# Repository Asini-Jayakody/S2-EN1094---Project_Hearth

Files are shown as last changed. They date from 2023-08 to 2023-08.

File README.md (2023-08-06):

# S2-EN1094
 Engineering Design Project Semester 02

Back in my early days in the department (second semester), I had the opportunity to work on an innovative project under the module EN1094. Our team decided to address a major issue that many people experienced at the time: the unavailability and high expense of fuel gasoline.
To solve this, we set out to create a long-term solution: a coconut shell stove.

Choosing this project was an eye-opening experience because we found the major problems involved with traditional coconut shell stoves. These stoves took an inordinate amount of time to light the charcoal, and once lit, they lacked an efficient mechanism of controlling the temperature.

With our collective enthusiasm and determination, we devised an ingenious solution: a hearth equipped with a DC fan to precisely control the heat output based on user input. The system operated on a 12V DC fan and incorporated a MAX6675 temperature sensor to monitor and maintain the desired temperature levels.

The result of our hard work was remarkable!

We succeeded in offering users six different temperature ranges, allowing them to select the most suitable one based on their specific needs. As we valued user interaction and feedback, we incorporated an OLED display and a buzzer as indicators to enhance the overall user experience.

Working in a team( with Dulini Himeka , Selani Indrapala , Jathurshan S. ) was an amazing experience! We collaborated closely, sharing ideas and supporting one another throughout the project's development. It was inspiring to witness the power of teamwork in overcoming challenges and achieving our common goal.

Presenting our hearth project at the end of the semester was a moment of immense pride and accomplishment. Not only we created an innovative solution to a real-world problem, but we also gained valuable insights into the realm of electronic design.

This project served as my first step into the world of electronic design, sparking my passion for technology and the limitless possibilities it offers. I am immensely grateful for the hands-on experience, the challenges, and the camaraderie that defined this journey.

Looking back, I cherish the memories of working together with my talented team, pushing the boundaries of creativity and engineering knowledge. The success of our hearth project on both technical and collaborative fronts has motivated me to pursue further electronic design projects, fostering a desire to continually learn and create impactful solutions for the world.

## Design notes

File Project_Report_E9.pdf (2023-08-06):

## Department of Electronic & Telecommunication Engineering

## University of Moratuwa

# Hearth

### Group EN09

200222K | HIMEKA S.H.D.
200232P | INDRAPALA S.A.
200239T | JATHURSHAN S.
200242V | JAYAKODY J.A.A.U.

This report is submitted for module EN1190

07th October 2022

## Abstract

The hearth regulates the temperature of the fire as per the user requirement by using the reading taken from the temperature sensor and regulating the DC fan speed accordingly. The hearth has a user interface which allows the user to turn a knob to their required temperature range and the selected range will be displayed on the OLED. Additionally, the hearth also has a buzzer going off if there are any abnormalities when functioning. The enclosure for the hearth was designed using SolidWorks and attention was given to the materials employed. The PCB was designed using Altium.

## Contents

### Introduction

The hearth takes into consideration the input temperature range by the user as well as the
current | temperature | reading | from | the
temperature sensor and will change the fan speed in order to bring the temperature into the users’ temperature range. The main components of the device are,
- ATmega328P-PU
- MAX6675 Temperature Sensor
- OLED
- 100K Potentiometer
- 12V DC fan
- L9110 Motor Driver Module
- 12V Power Pack

The device gives the user an option of 6 temperature ranges and has a buzzer and a display to notify the user of the selected temperature range and if there is an issue in the functionality.

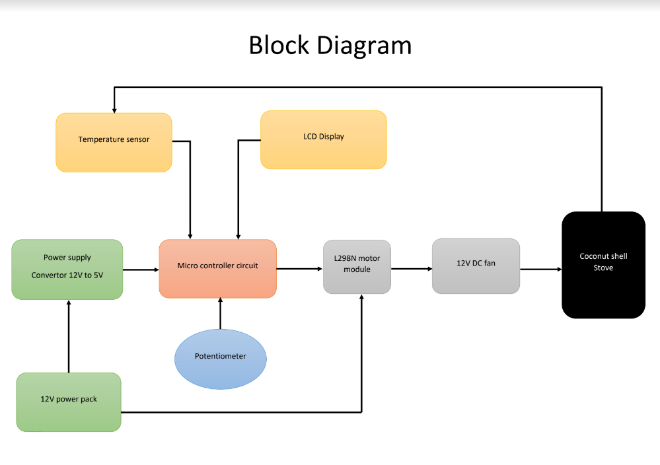
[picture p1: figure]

Figure 1.1: Block Diagram of the Device

### Product Description

Design Idea

Given the shortage of gas cylinders and the hike of gas cylinder prices in the recent past in Sri Lanka, most people have been turning to using electric induction cookers or hearths. Since electricity prices as well as induction cooker prices have also increased, most households have been using traditional hearths.

Motivation

However, these hearths have potential to be improved to make the cooking experience more user friendly. The existing market products can be seen to lack the following features,

- User must keep blowing into the flame to control the flame. Even the hearths with DC fans have an unreliable increase and reduction in temperatures such that the user must consistently be present to adjust fan speeds.
- Soot depositions on cooking utensils and the stove.
- Cleaning the ash leftovers after usage.
- Smokes released are disturbing.

Who Benefits?

Our device would cater to most lower to middle class households as it could reduce the costs associated with gas cylinders as well as electricity.

### Product Idea Validation

Hearths have a lot of room for improvement. However, the main problem we chose to focus on was the fact that the user must be in constant vicinity of the hearth to ensure that the heat from the fire is regulated at the needed level. This would be a waste of time for the consumer.

Therefore, our solution was to build a hearth with a DC fan which would regulate the heat in the needed level once the user has input their requirement.

To ensure that this was a requirement of our target market we conducted a survey through which we collected the following data.

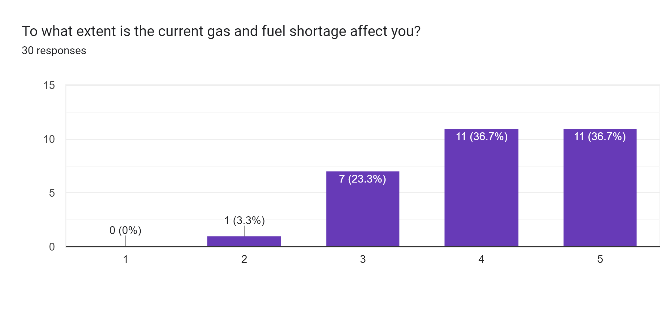
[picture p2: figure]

Figure 3.1: The extent to which users were affected by the gas shortage.

As seen by Figure 3.1, more than 50% of users were highly affected by the gas shortage. Therefore, an alternative for gas cookers is necessary.

Figure 3.2: Will the user buy our product?

On explaining the product, we had in mind, most users showed positive responses whereas a few were unsure but none of the users believed that the product was not needed.

Figure 3.3: User needs.

We then took this opportunity to check what the user expected of this product and on designing the product we took into consideration most of these factors.

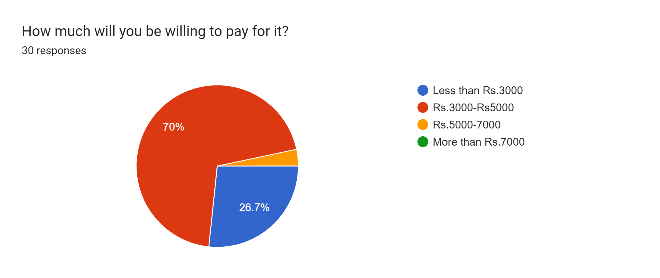
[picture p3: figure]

Figure 3.4: Product cost

Finally, we asked the users what cost they would be willing to incur for this product. As per Figure 3.4, the price range was determined to be between Rs 3,000 and Rs 5,000. However, this survey was conducted approximately 2 months prior and did not take into consideration the import bans as well as the inflation. Currently, the market price for similar products range between Rs 7,000 and Rs 11,000. Therefore, the price for the product may have to be reconsidered to around Rs 8,000 or more.

### Development

The development of this project was done in four stages. They are,

1. Circuit Design
2. Arduino Implementation
3. Breadboard Implementation with the

Microcontroller

Circuit Design

Initially a schematic with all the circuit components was built using the EasyEDA software. Afterwards, the connections between each component were made.

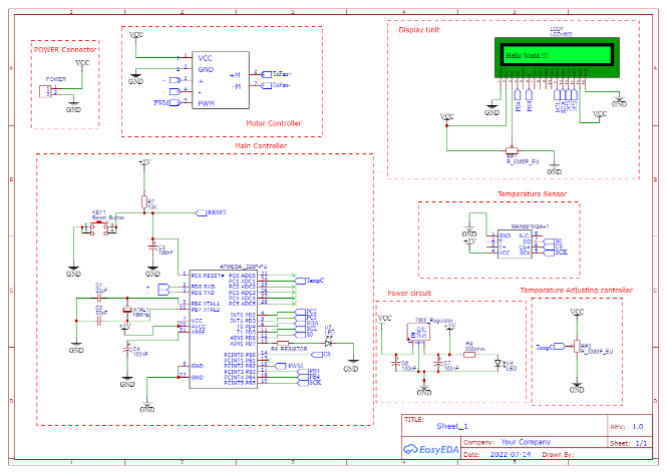
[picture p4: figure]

Figure 4.1: Circuit components

Arduino Implementation

Once all the circuit connections were made, the circuit was implemented on an Arduino step by step to check its functionality.

Initially, instead of using a DC fan, we placed LED bulbs in order to check whether the brightness can be changed for different temperature levels.

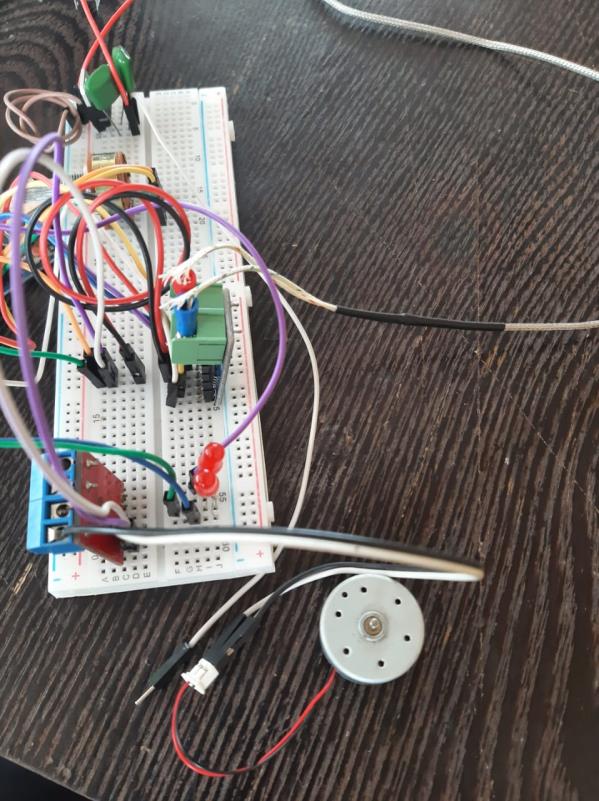
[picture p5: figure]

Figure 4.2: Testing using LED’s

After this proved to be successful, we next added the DC fan to the circuit as well.

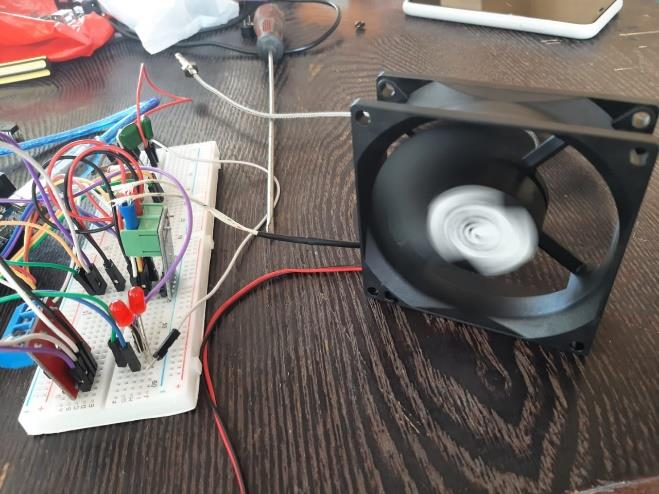
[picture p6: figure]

Figure 4.3: Testing the fan

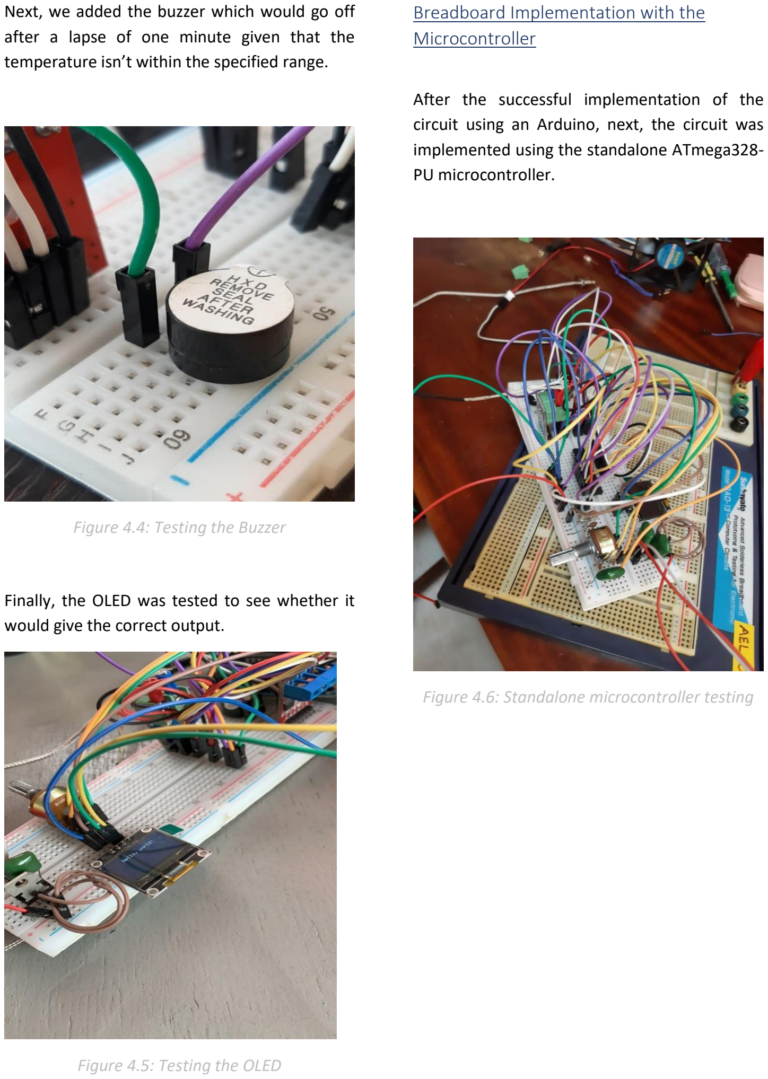
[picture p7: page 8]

Next, we added the buzzer which would go off after a lapse of one minute given that the temperature isn’t within the specified range.

Figure 4.4: Testing the Buzzer

Finally, the OLED was tested to see whether it would give the correct output.

Figure 4.5: Testing the OLED

Breadboard Implementation with the Microcontroller

After the successful implementation of the circuit using an Arduino, next, the circuit was implemented using the standalone ATmega328-PU microcontroller.

Figure 4.6: Standalone microcontroller testing

### PCB Design

PCB design was done using Altium software. In the schematic design, all the components and connections were done according to our circuit design and Arduino implementation. The design was a single layer PCB.

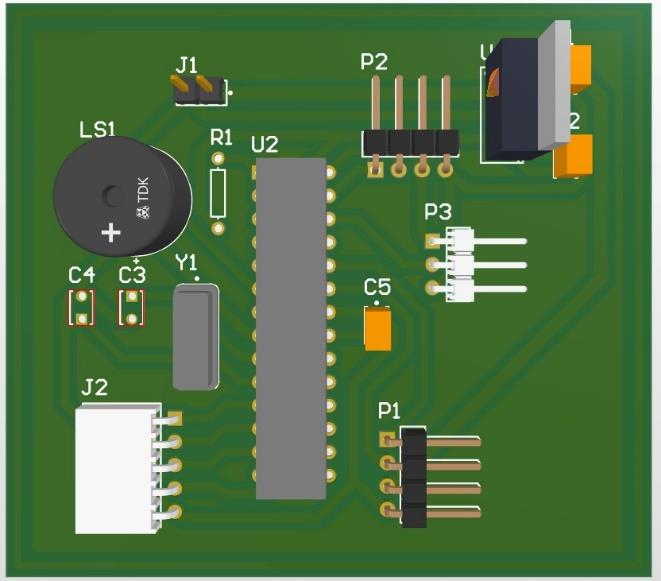
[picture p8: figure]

Figure 5.1: 3D view of the PCB

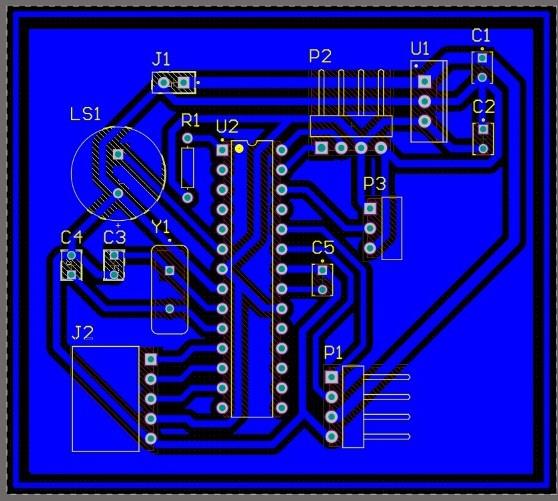
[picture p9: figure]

Figure 5.2: PCB design

For the 12V power supply 1.5mm trace width was selected and for the 5V power supply 1mm trace width was selected. The ground had a 1.5mm trace width and the signal lines had a 0.8mm trace width.

These measurements were made taking into
consideration | the | power | and | current
consumption of the circuit.

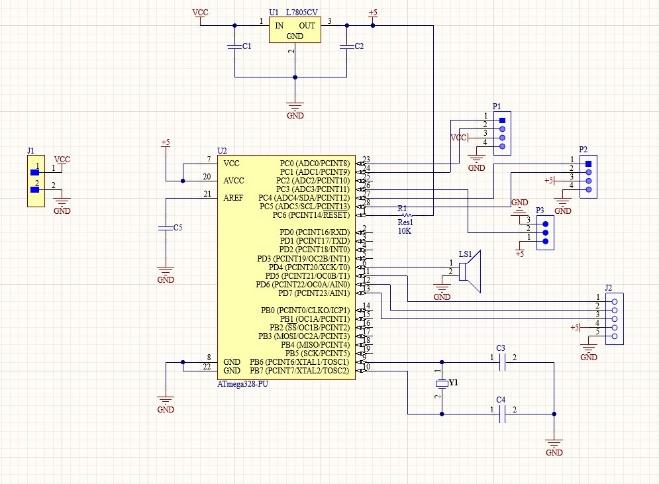
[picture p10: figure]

Figure 5.3: Schematic

### Enclosure Design

Considering the existing models in the industry, we made an initial sketch on how we wanted the hearth to look like.

To ensure that the cooking pots fit perfectly and to ensure efficient heat transfer, the opening of the hearth was decided to be conical in shape.

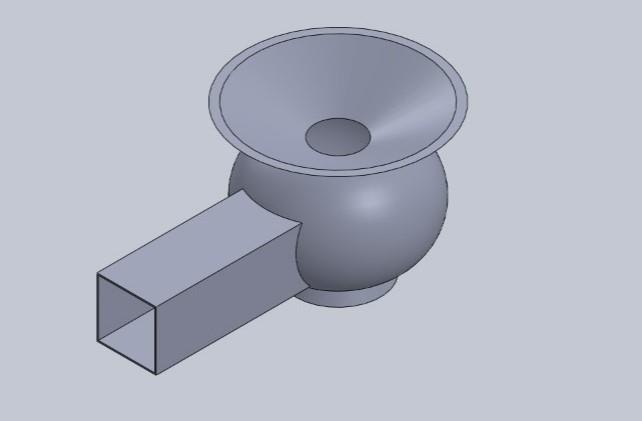
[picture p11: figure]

Figure 6.1: Hearth Enclosure

A spherical structure was selected for the base of the hearth as it would be a stronger structure than a cylindrical base.

It was decided that this structure should be made using aluminium as it would pose less of a risk than normal clay pots which are susceptible to cracking. Since aluminium tends to heat up and could be harmful to the user, it was decided that a wooden box should surround the aluminium structure.

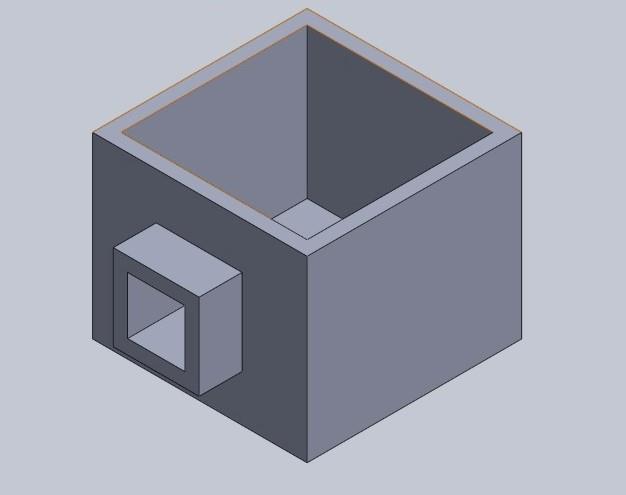
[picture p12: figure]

Figure 6.2: Wooden Enclosure

An opening was also made on the Aluminium structure to which the fan was attached. This structure had an opening at the end so that the fan had sufficient access to the atmosphere.

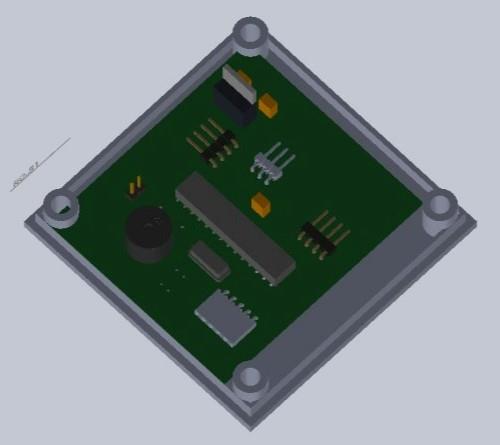
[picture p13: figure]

Figure 6.3: PCB Enclosure

Figure 6.4

Figure 6.5

On top of the fan enclosure the PCB enclosure was attached, and this enclosure was made taking into consideration the PCB design.

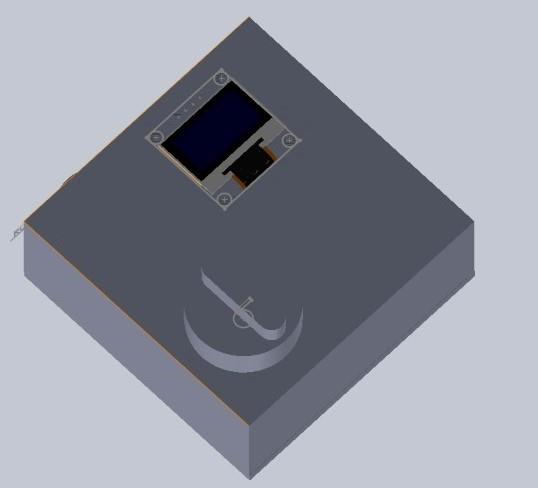
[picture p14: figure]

Figure 6.6: Top view of the PCB enclosure

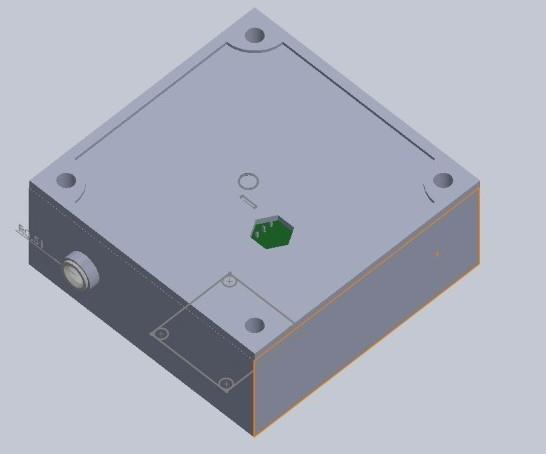
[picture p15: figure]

Figure 6.7: Bottom view of the PCB enclosure

For the PCB enclosure, 2 openings had to be made on top to accommodate the LCD as well as the potentiometer by which the user can choose the temperature range. Another opening was required at the bottom of the enclosure to connect the fan as well as to accommodate the temperature sensor.

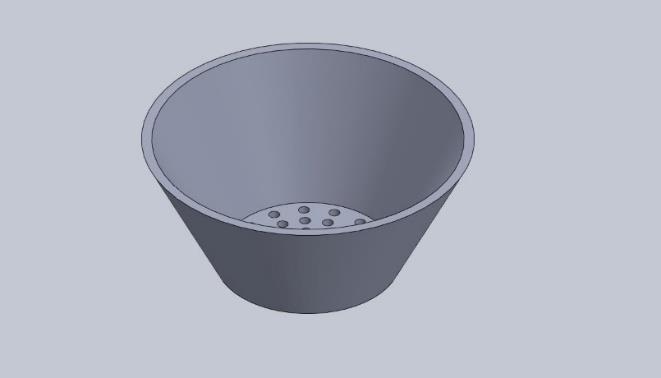
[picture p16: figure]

Figure 6.8: Removable opening in the enclosure

One user requirement was to make the removal of coconut husks easy. Therefore, another enclosure was placed at the opening to easily remove and replace and holes at the bottom to ensure that wind still passed through. To protect this enclosure from coconut husks, a mesh was

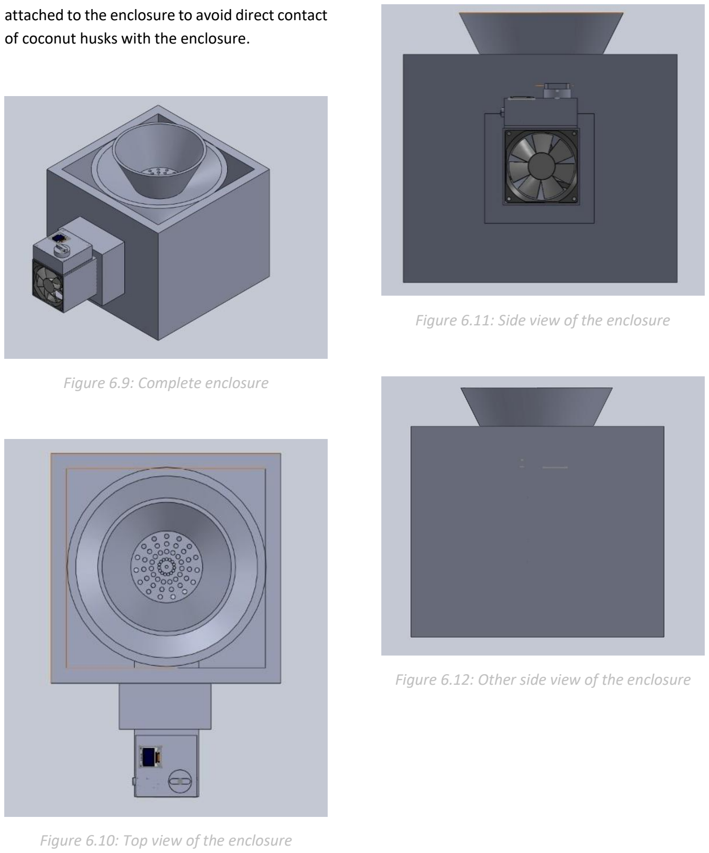
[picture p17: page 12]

attached to the enclosure to avoid direct contact of coconut husks with the enclosure.

Figure 6.9: Complete enclosure

Figure 6.10: Top view of the enclosure

Figure 6.11: Side view of the enclosure

Figure 6.12: Other side view of the enclosure

### List of Components

Component | Quantity
ATmega328-PU | 1
L7805CV | 1
100 nf capacitor | 3
22 pf capacitor | 2
16 MHz crystal oscillator | 1
Piezoelectric buzzer | 1
10K resistor | 1
2 pin headers | 1
4 pin headers | 2
3 pin headers | 2
5 pin headers | 1
230V-12V Power regulator | 1
MAX6675 Temperature sensor | 1
L9110 Motor module | 1
12V DC fan | 1
OLED | 1
100K Potentiometer | 1

ATmega328-PU

The high-performance Pico Power 8bit AVR RISCbased microcontroller combines 32KB ISP flash memory with read-while-write capabilities, 1024B EEPROM, 2KB SRAM, 23 general purposes I/O lines, 32 general purpose working registers, three flexible timer/counters with compare modes, internal and external interrupts, serial programmable USART, a byte-oriented 2-wire serial interface, SPI serial port, a 6-channel 10-bit A/D converter (8-channels in TQFP and QFN/MLF packages), programmable watchdog timer with internal oscillator, and five software selectable power saving modes. The device operates between 1.8-5.5 volts. This is the main component of the microcontroller circuit. Program is coded and fetched into this.

MAX6675 Temperature Sensor

The | MAX6675 | performs | cold-junction
compensation and digitizes the signal from a type-K thermocouple. The data is output in a 12-bit resolution, SPI-compatible, read-only format. This converter resolves temperatures to 0.25°C, allows readings as high as +1024°C, and exhibits thermocouple accuracy of 8 LSBs for temperatures ranging from 0°C to +700°C. The MAX6675 is available in a small, 8-pin SO package.

Figure 7.1: Temperature Sensor

Considering the components used, the existing products in the market as well as the enclosure, we determined that our product lifetime is 3 years.

L9110 Motor Driver Module

L9110 Module can control up to 2 DC motors with directional and speed control. Previously we had selected the L298 Motor Driver Module however it has a higher power consumption. Therefore, we chose to switch to this motor driver module instead.

This is used to control the speed of the 12V DC fan.

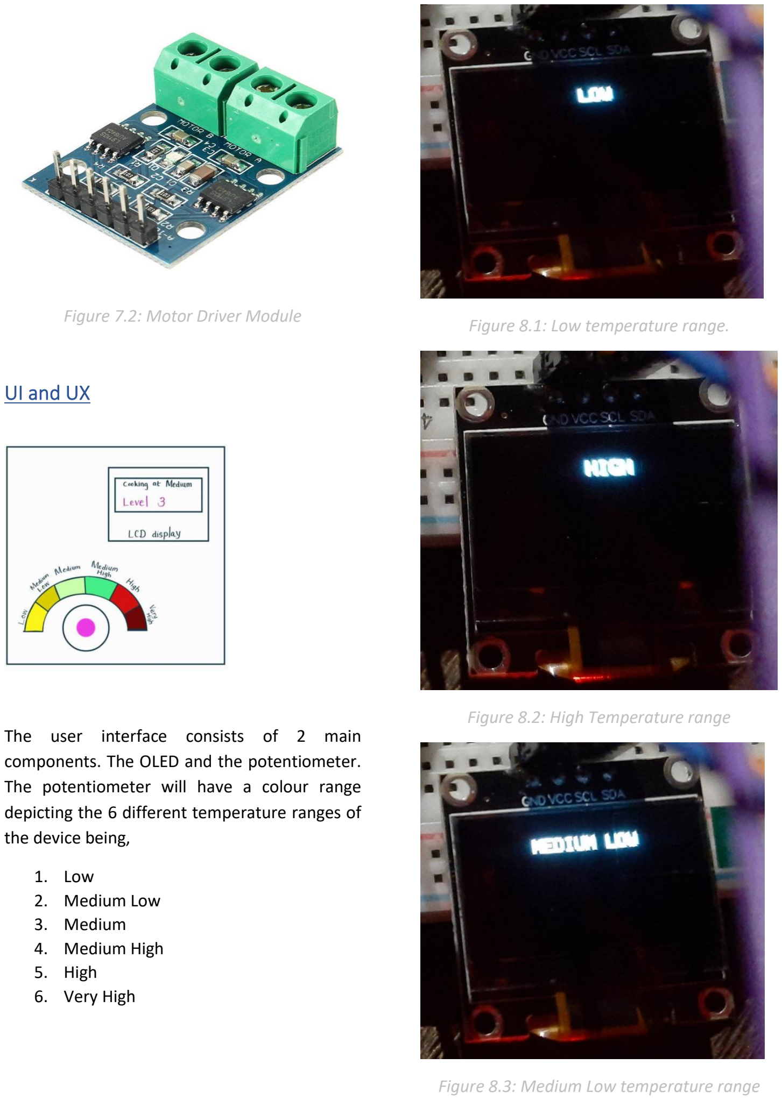
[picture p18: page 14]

Figure 7.2: Motor Driver Module

### UI and UX

The user interface consists of 2 main components. The OLED and the potentiometer. The potentiometer will have a colour range depicting the 6 different temperature ranges of the device being,

1. Low
2. Medium Low
3. Medium
4. Medium High
5. High
6. Very High

Figure 8.1: Low temperature range.

Figure 8.2: High Temperature range

Figure 8.3: Medium Low temperature range

Once one of these ranges are selected by the potentiometer, the output will be shown on the OLED.

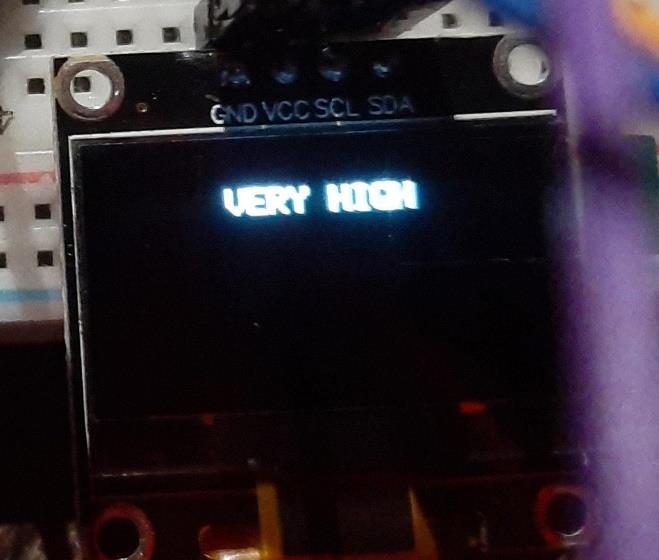
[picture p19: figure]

Figure 8.4: Very High temperature range

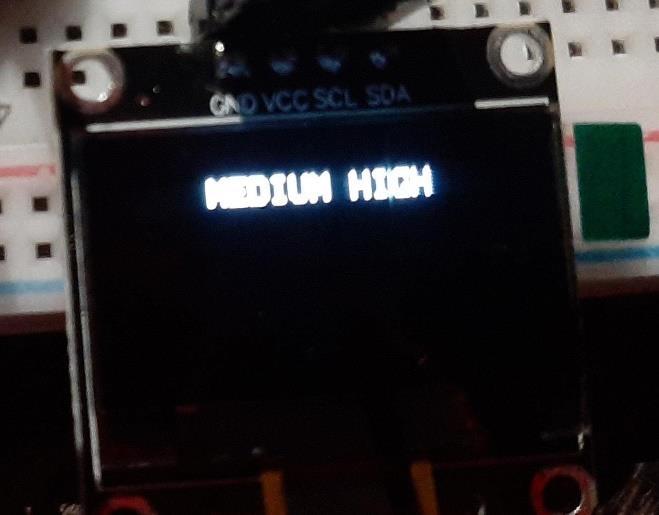
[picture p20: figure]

Figure 8.5: Medium High temperature range

### Testing

To ensure the functionality of the system, several tests were conducted both for individual components as well as the entire system. The tests conducted are as follows,

- Individual testing of the component

functionality using Arduino (mentioned

above).

- Testing the heat tolerance of the hearth

enclosure (Mentioned below).

- Testing the fan speeds for different

temperature ranges by hardcoding input

temperatures from the sensor.

- Testing buzzer functionality by hard

coding erroneous values.

- Checking different temperature ranges

for different potentiometer inputs. This

was also used to check whether the

OLED was displaying the correct outputs.

- Testing whether the temperature sensor

was giving correct outputs by using 2

different temperature sensors.

### Results

When the device is initially switched on, the LCD will display “Hello. Choose a Temperature Range.” Then the user will have to turn the knob to one of the 6 temperature ranges specified on the enclosure.

Once a temperature range is selected, the LCD will display the selected temperature range. Meanwhile, the temperature sensor will read the current temperature of the coconut husks and will switch on the DC fan to a specified speed to bring the temperature to the selected level.

If the temperature is too high, the fan will switch off and the temperature will drop and once it drops past the selected temperature level, the fan will restart.

In the case that there are some unforeseen circumstances, and the temperature remains too high despite the fan being turned off, the buzzer will go off after a lapse of 1 minute. Similarly, if the temperature doesn’t increase despite the fan being turned on, the buzzer will go off again after a lapse of one minute.

### Further Improvements

The device can be further improved to accommodate other user requirements such as,

- A system to effectively dispose of the

smoke accumulated from the hearth.

- Creating an app so that the user can

complete the same tasks through the

app and get notifications for abnormal

functionality.

### Marketing and Sales

Product Packaging

Since the product is not fragile nor does it have any technical specifications for storage, packaging can be done using a normal cardboard box with bubble wrap. A leaflet will also be given with instructions on how to use the hearth.

Maintenance and repair

The warranty period for the hearth will be a period of 3 years and for any issues after sale services will be provided through either repair of the existing hearth or replacing it with a new hearth.

Disposal

Some components, such as the aluminium can be reused or recycled at the end of the product lifetime and therefore ways in which it can be reused will be mentioned on the leaflet. However, other electronic components will have to be disposed of in a safe manner and instructions for disposal will be given to the user in the leaflet.

### Discussions

Determining the material of the hearth.

A main concern when determining the material of the hearth was the melting point or cracking point of the material. Using clay for the pot would mean that the pot would crack at our maximum temperatures but there was also a concern as to whether aluminium would melt at our highest temperature range. Therefore, the material was tested by holding it to a high flame and observing its’ results. No negative results were observed.

OLED display terms were overlapping.

When changing the temperature range from one user input to another, the display would overlap the terms for a period of 2 seconds before completely changing. This was because the outputs were of different sizes and therefore for a complete rewrite of the output, padding needed to be added so that all outputs were of the same size.

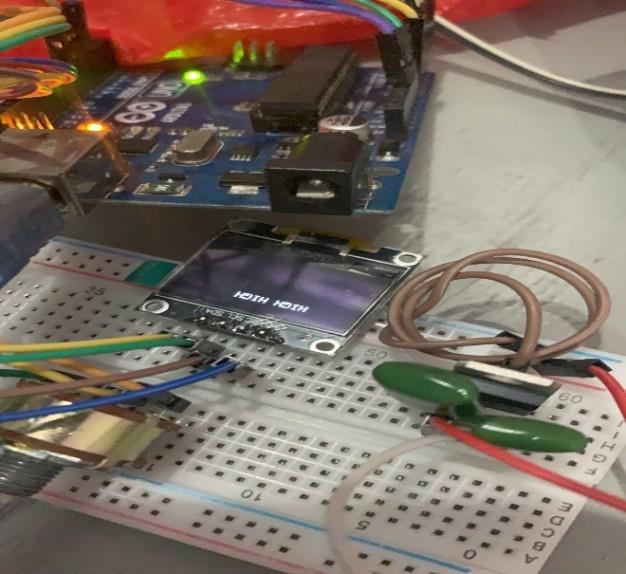
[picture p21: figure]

Figure 10.1: An overlap of “VERY HIGH” with “HIGH”

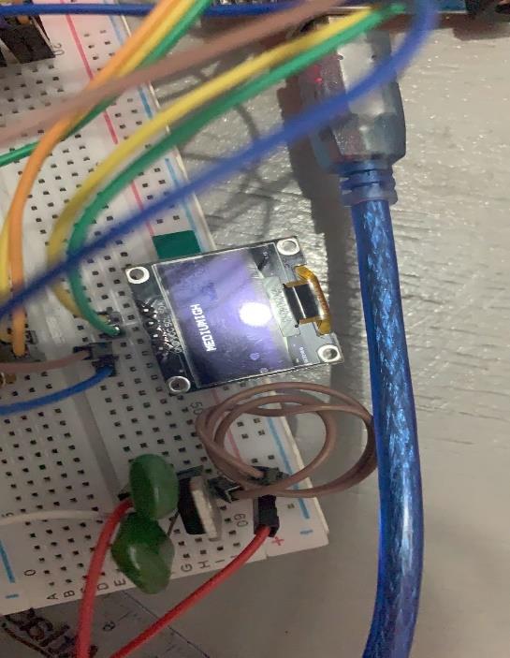
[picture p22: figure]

Figure 10.2: An overlap of “MEDIUM” with “HIGH”

Determining the count for the buzzer.

The buzzer is said to go off at the time of an issue. But we needed to determine the time needed for the buzzer to go off. Our code gets temperature readings every one second. To move the temperature from one range to another it would take some time and the time taken would depend on many factors. Through testing we determined that the best possible time lapse to wait until the buzzer goes off is 10 minutes as some temperature range shifts would take this amount of time whereas if there was an issue, a 10-minute lapse won’t be too disastrous.

### Acknowledgement

We would like to extend our gratitude to our lecturers who provided us with the required technical knowledge and guidance which served as the foundation for this project.

### Bibliography

Guide for I2C OLED Display with Arduino. Retrieved from

https://randomnerdtutorials.com/guide-foroled-display-with-arduino/ (https://randomnerdtutorials.com/guide-for-oled-display-with-arduino/)

Spherical and Cylindrical Pressure Vessels. Retrieved from

https://www.wermac.org/equipment/pressurev essel.html (https://www.wermac.org/equipment/pressurevessel.html)

Getting Started With the ATMega328P. Retrieved from

https://www.instructables.com/Getting-Started-With-the-ATMega328P/ (https://www.instructables.com/Getting-Started-With-the-ATMega328P/)

Temperature based Fan Speed Control. Retrieved from https://create.arduino.cc/projecthub/embeddedlab786/temperature-based-fan-speed-control-945f9d (https://create.arduino.cc/projecthub/embeddedlab786/temperature-based-fan-speed-control-945f9d)

WHEN TO USE ALUMINUM VS STAINLESS STEEL. Retrieved from

https://www.kloecknermetals.com/blog/whento-use-aluminum-vs-stainlesssteel/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 s%20steel%20vs,over%20steel%20in%20cold%2 0temperatures. (https://www.kloecknermetals.com/blog/when-to-use-aluminum-vs-stainless-steel/)

TODD OPPENHEIMER. The Laws of Thermo-Culinary Dynamics. Retrieved from

https://craftsmanship.net/sidebar/the-laws-ofthermo-culinarydynamics/#:~:text=Aluminum%20is%20even%2 0more%20aggressive,than%20its%20equivalent %20in%20clay. (https://craftsmanship.net/sidebar/the-laws-of-thermo-culinary-dynamics/)

Maureen. Induction Cooking Temperature Guide With Settings & Chart. Retrieved from

https://apreparedkitchen.com/inductioncooking-temperature-settings/ (https://apreparedkitchen.com/induction-cooking-temperature-settings/)

### Appendices

Budget

Component | Quantity | Cost
ATmega328-PU | 1 | 1700
L7805CV | 1 | 60
100 nf capacitor | 3 | 15
22 pf capacitor | 2 | 20
16 MHz crystal oscillator | 1 | 40
Piezoelectric buzzer | 1 | 240
10K resistor | 1 | 45
2 pin headers | 1 | 90
4 pin headers | 2
3 pin headers | 2
5 pin headers | 1
230V-12V Power regulator | 1 | 1380
MAX6675 Temperature sensor | 1 | 1350
L9110 Motor module | 1 | 200
12V DC fan | 1 | 620
OLED | 1 | 1000
100K Potentiometer | 1 | 60
PCB | | 550
Enclosure | | 2000
Total | | 9370

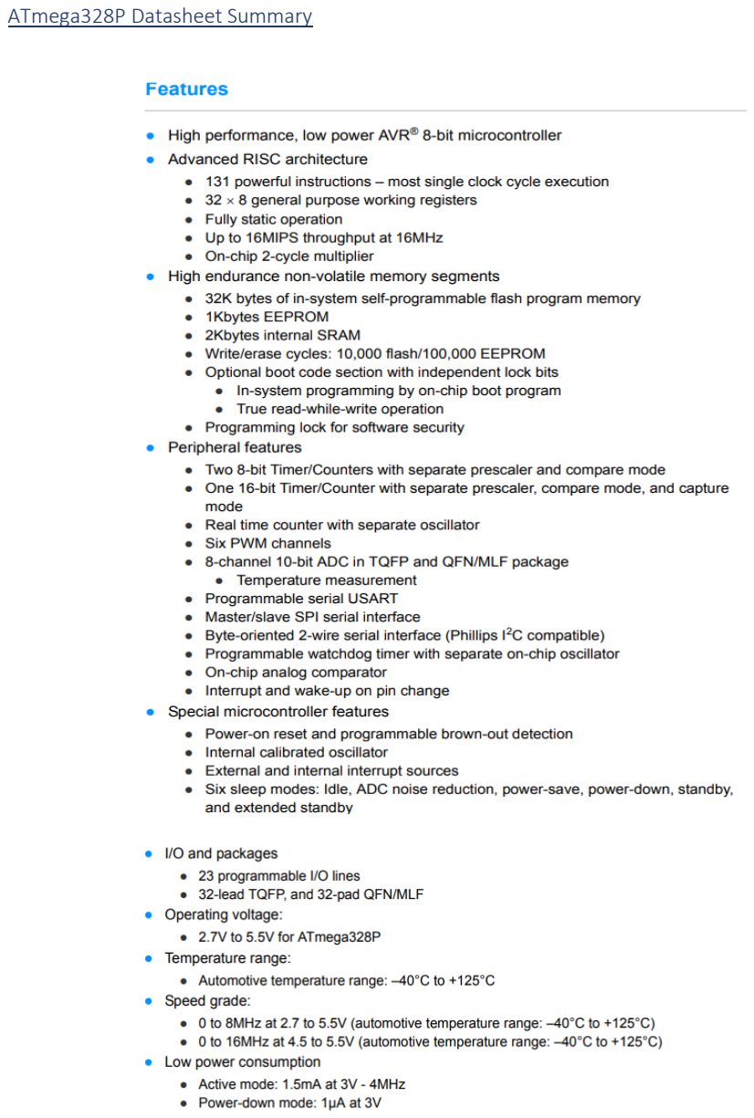
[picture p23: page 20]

ATmega328P Datasheet Summary

MAX6675 Temperature Sensor Datasheet Summary

Code

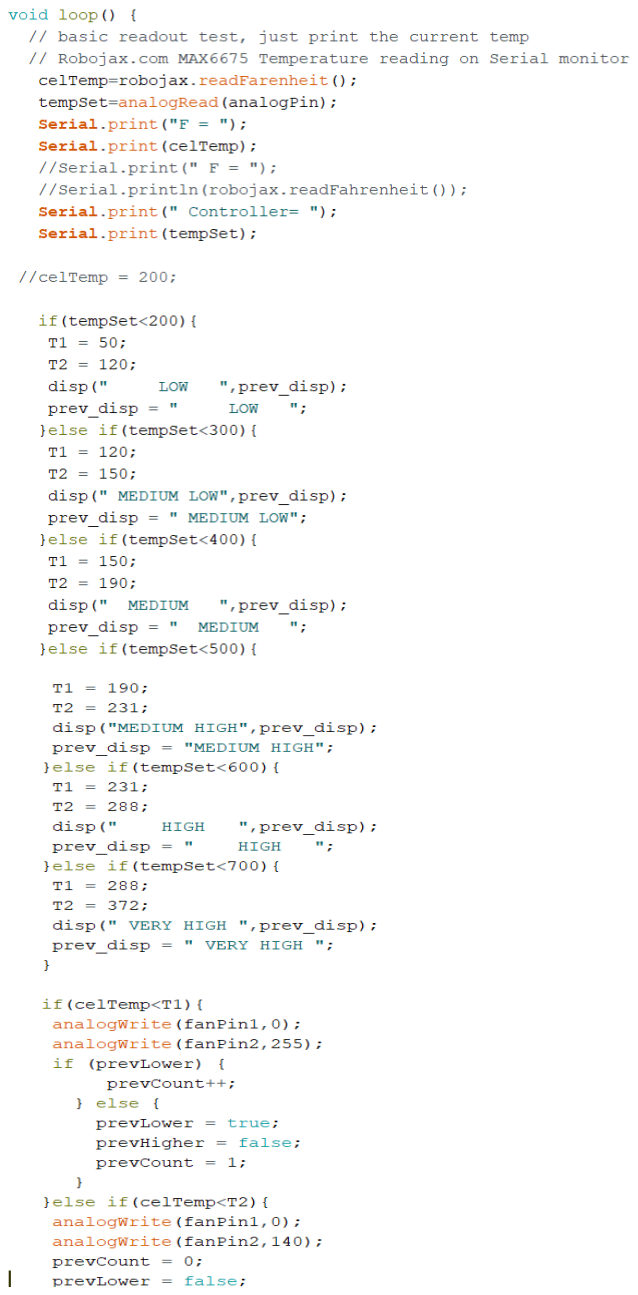
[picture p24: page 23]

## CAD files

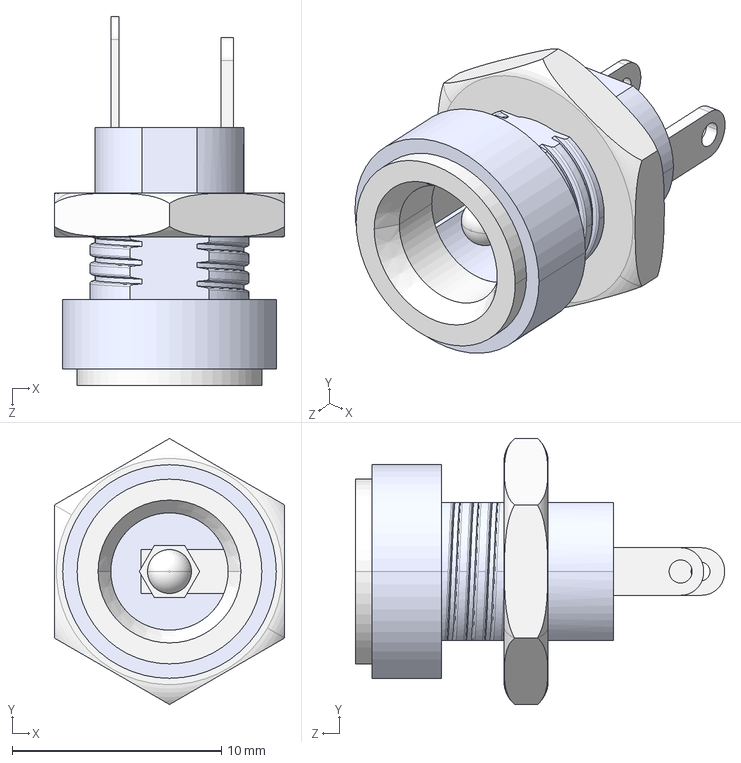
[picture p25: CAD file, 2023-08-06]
Solidworks/Solidworks/DC Jack Panel Mount ASSY.STEP
11.0 x 12.7 x 17.6 mm
DC Jack Panel Mount Base
DC Jack Panel Mount Nut

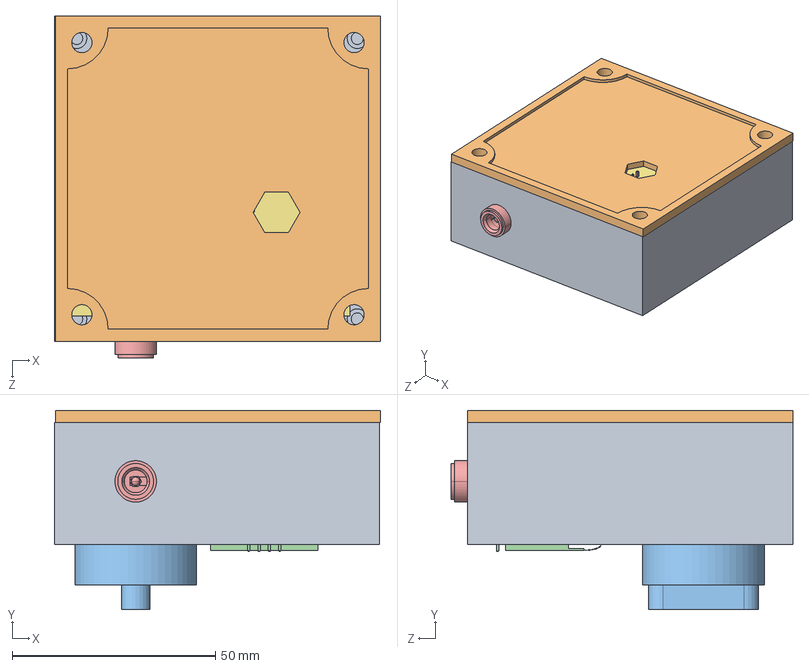
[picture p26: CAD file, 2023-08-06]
Solidworks/Solidworks/Ourbox.SLDASM
80.2 x 49.0 x 84.1 mm
Newupper
Newlower
User Library-128x64I2COLEDDisplayAdafruit
DC Jack Panel Mount Base.STEP
DC Jack Panel Mount Nut.STEP
Extruded.step
Extruded-0.step
Extruded-1.step
Extruded-2.step
Extruded-3.step
MTSW-103-08-X-S-229-RA.step
6130xx11021_PIN.step x 8
61300411021-4.step x 2
Body.step
Plus_Sign.step
TDK_Logo.step
SSQ-105-02-X-S-RA.step
TSW-102-07-L-S_body.step
T-1S6-07-TSW-1-07-2-S.step
Samtec.step
Extruded-5.step x 3

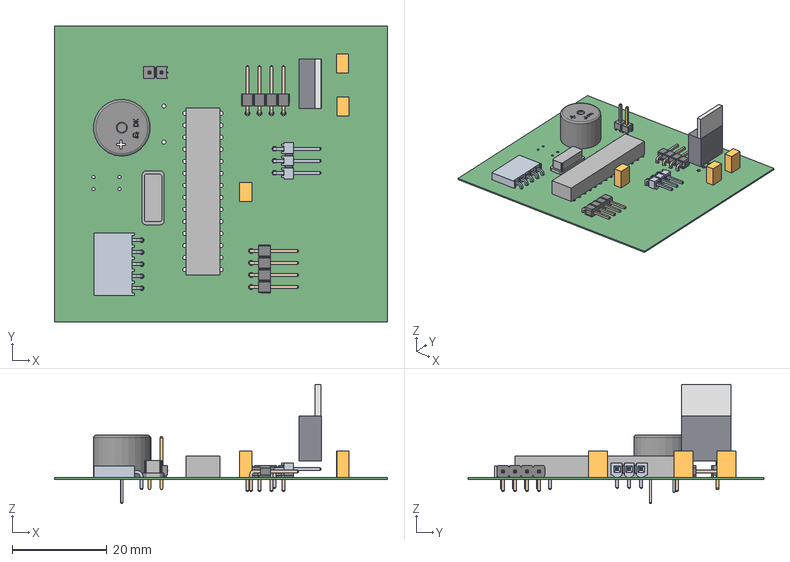
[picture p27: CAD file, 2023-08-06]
PCB_Project_Hearth/PCB3.step
70.4 x 62.5 x 25.2 mm
Extruded x 8
MTSW-103-08-X-S-229-RA
6130xx11021_PIN x 8
Plus_Sign
TDK_Logo
SSQ-105-02-X-S-RA
TSW-102-07-L-S_body
T-1S6-07-TSW-1-07-2-S
Samtec
C4
C3

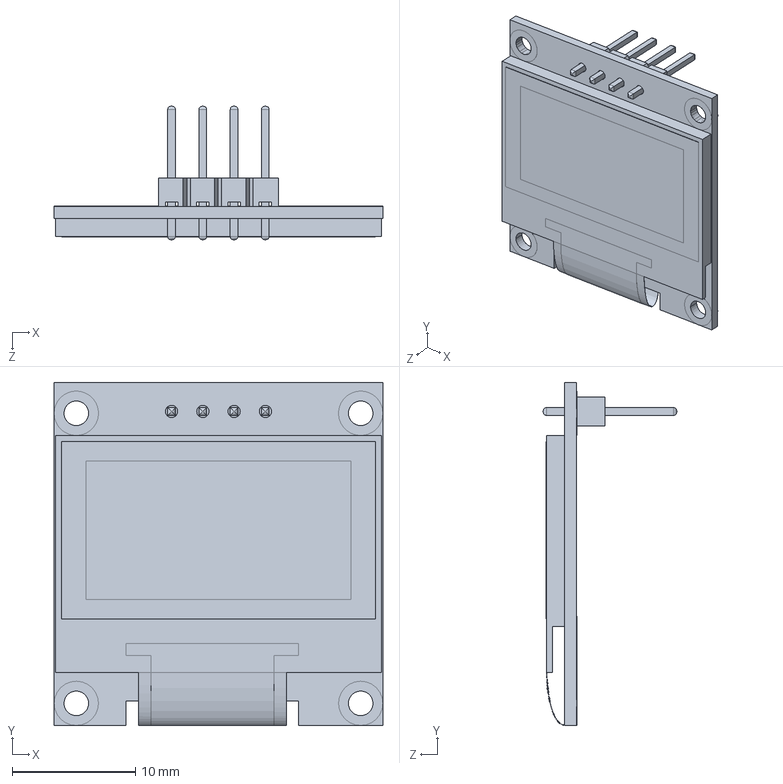
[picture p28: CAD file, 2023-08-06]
Solidworks/Solidworks/User Library-128x64I2COLEDDisplayAdafruit.sldprt
26.7 x 27.9 x 10.8 mm

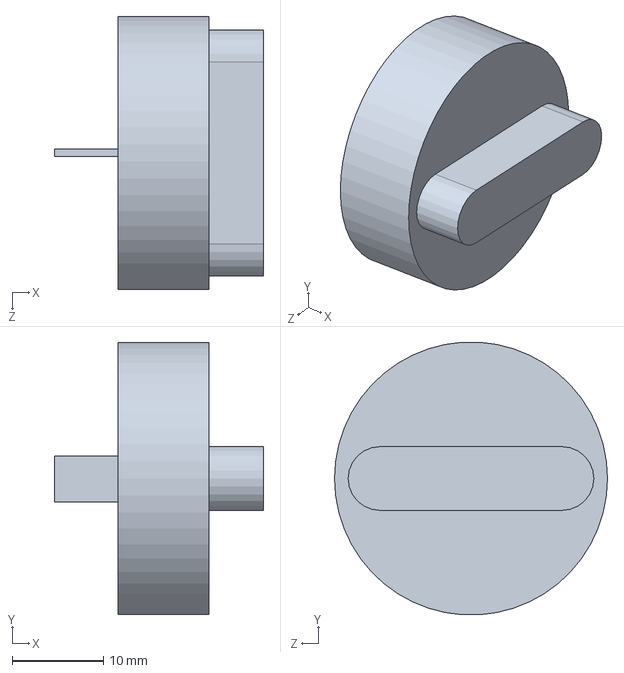
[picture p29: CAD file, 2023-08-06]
Solidworks/Solidworks/Part3.SLDPRT
23.0 x 29.9 x 30.0 mm

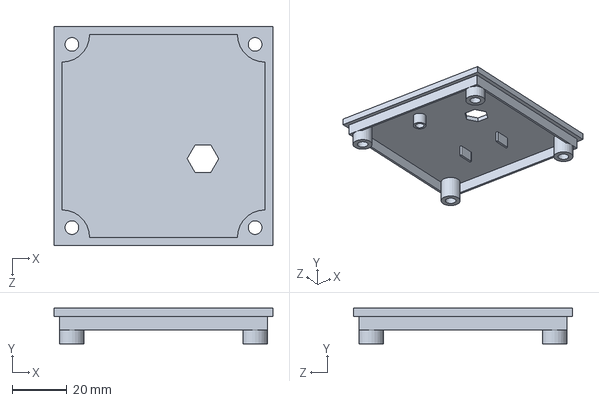
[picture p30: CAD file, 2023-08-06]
Solidworks/Solidworks/Newlower.SLDPRT
80.0 x 13.0 x 80.0 mm

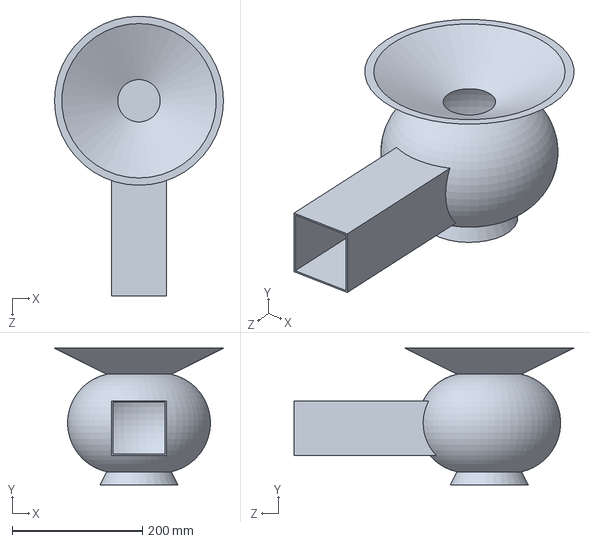
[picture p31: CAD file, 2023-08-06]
Solidworks/Solidworks/pOTNEW.SLDPRT
260.0 x 210.0 x 430.0 mm

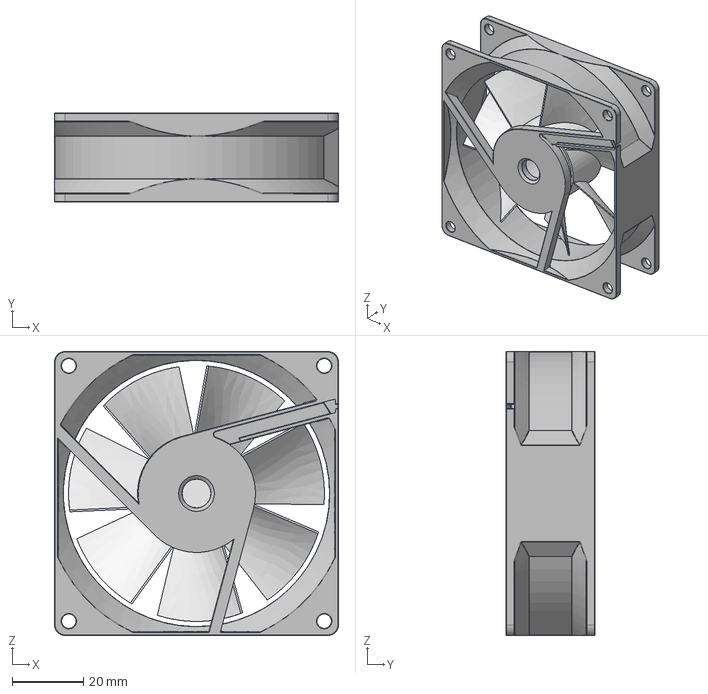
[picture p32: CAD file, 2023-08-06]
Solidworks/Solidworks/80MM_FAN.step
79.5 x 25.0 x 79.5 mm

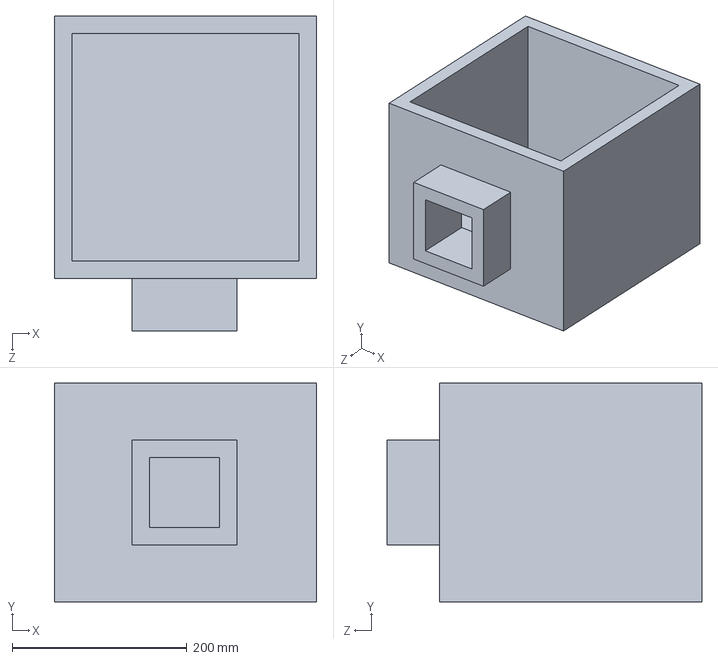
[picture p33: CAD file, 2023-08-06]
Solidworks/Solidworks/Box.SLDPRT
300.0 x 250.0 x 360.0 mm

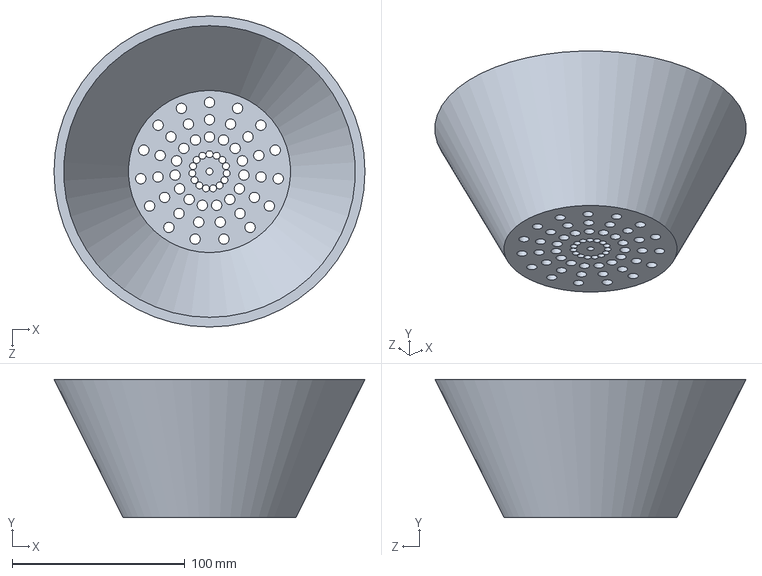
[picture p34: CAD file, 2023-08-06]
Solidworks/Solidworks/COAL.SLDPRT
180.0 x 80.0 x 180.0 mm

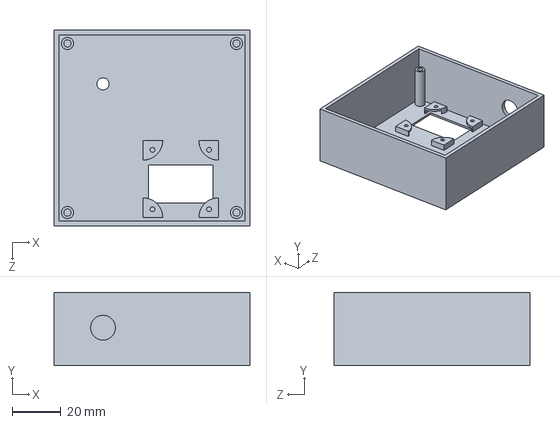
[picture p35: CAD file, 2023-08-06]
Solidworks/Solidworks/Newupper.SLDPRT
80.0 x 30.0 x 80.0 mm
